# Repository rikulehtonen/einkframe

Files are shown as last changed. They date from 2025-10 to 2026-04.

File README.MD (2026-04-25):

# E-ink Art Frame - Low-Power Picture Display

A low-power digital art frame that cycles through images stored on an SD card, displayed on a 6-color e-paper screen. The display retains its image indefinitely without power, making it ideal for an always-on picture frame. Supports both Waveshare and Pimoroni Inky Impression panels.

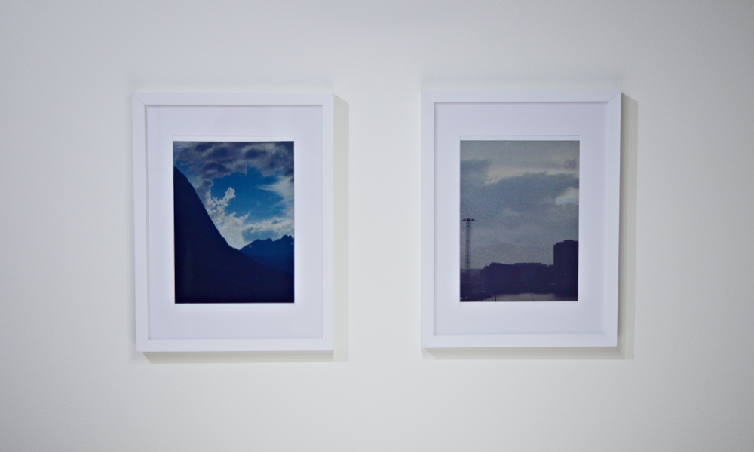
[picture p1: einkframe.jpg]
E-ink frame photo


## Features

- Cycles through images stored on a microSD card
- 6-color e-paper display: black, white, yellow, red, blue, green
- Ultra-low power — display holds image without power between updates
- Three firmware variants: 4-inch Arduino R4, 13.3-inch Waveshare ESP32, 13.3-inch Inky Impression ESP32
- Custom PCB hardware designs included

---

## Hardware Variants

### 4-inch (Waveshare EPD-4in0e) — Arduino R4
- **Resolution:** 400 × 600 px
- **Controller:** Arduino UNO R4
- **Update interval:** every 4 minutes
- Firmware: [waweshare_Arduino_R4_4inch/](waweshare_Arduino_R4_4inch/)

### 13.3-inch (Waveshare EPD-13in3e) — ESP32
- **Resolution:** 1200 × 1600 px
- **Controller:** ESP32 (with PSRAM)
- **Update interval:** every 13 hours (deep sleep between updates)
- Firmware: [waweshare_ESP32_13inch/](waweshare_ESP32_13inch/)

### 13.3-inch (Pimoroni Inky Impression) — ESP32
- **Resolution:** 1200 × 1600 px
- **Controller:** ESP32 (with PSRAM)
- **Update interval:** every 13 hours (deep sleep between updates)
- **Display:** Pimoroni Inky Impression 13.3" (uses the same underlying panel as the Waveshare variant)
- **Difference from Waveshare variant:** skips the initial screen clear before rendering, avoiding a full white flash on each update
- Firmware: [inky_ESP32_13inch/](inky_ESP32_13inch/)

---

## Repository Structure

```
├── waweshare_Arduino_R4_4inch/   # Arduino R4 firmware for 4-inch Waveshare display
├── waweshare_ESP32_13inch/       # ESP32 firmware for 13-inch Waveshare display
├── inky_ESP32_13inch/            # ESP32 firmware for 13-inch Pimoroni Inky Impression
├── image_conversion/             # Python script to convert images for the display
│   ├── convert.py
│   ├── input/                    # Place source PNG files here
│   └── output/                   # Converted .bin files are written here
├── hardware/
│   ├── controller/               # KiCad controller PCB design + gerbers
│   └── shield/                   # KiCad shield PCB design
├── documentation/                # Waveshare datasheets and manuals
└── demo/                         # Vendor-provided reference demos
```

---

## Getting Started

### 1. Convert Images

Images must be pre-converted to a packed binary format before being loaded onto the SD card.

**Requirements:** Python 3, Pillow (`pip install Pillow`)

```bash
cd image_conversion
# Place your PNG files in the input/ folder
python convert.py
# Output .bin files will appear in output/
```

The script quantizes each image to the 6-color palette, then packs 2 pixels per byte (4 bits each) to produce a `.bin` file. A palette-quantized `.bmp` preview is also saved alongside each `.bin`.

**Image dimensions must match the display:**
- 4-inch: 400 × 600 px
- 13-inch: 1200 × 1600 px

### 2. Prepare the SD Card

Copy the converted `.bin` files to the root of a FAT32-formatted microSD card, then create two text files:

**`files.txt`** — comma-separated list of filenames to display:
```
image1.bin,image2.bin,image3.bin
```

**`config.txt`** — current image index (start with `0`):
```
0
```

The firmware reads the current index from `config.txt`, displays that image, increments the index (wrapping around at the end of the list), and writes it back before sleeping.

### 3. Flash the Firmware

Open the appropriate sketch in the Arduino IDE:
- **4-inch Waveshare:** `waweshare_Arduino_R4_4inch/Arduino_R4_4inch.ino`
- **13-inch Waveshare:** `waweshare_ESP32_13inch/waweshare_ESP32_13inch.ino`
- **13-inch Inky Impression:** `inky_ESP32_13inch/inky_ESP32_13inch.ino`

Flash to your board using the Arduino IDE.

---

## Pin Connections

### Arduino R4 (4-inch display)

| Signal | Arduino Pin |
|---|---|
| SCK | 13 |
| MOSI | 11 |
| EPD CS | 10 |
| DC | 9 |
| RST | 8 |
| BUSY | 7 |
| PWR | 6 |
| SD CS | 4 |

### ESP32 (13-inch Waveshare and Inky Impression — same pins)

| Signal | ESP32 Pin |
|---|---|
| SCK | 18 |
| MOSI | 23 |
| MISO | 19 |
| EPD CS_M | 2 |
| EPD CS_S | 13 |
| DC | 14 |
| RST | 0 |
| BUSY | 26 |
| PWR | 25 |
| SD CS | 17 |

The 13-inch display uses dual SPI chip selects (CS_M and CS_S) to address the left and right halves of the panel independently.

---

## Color Palette

| Color  | 3-bit Code | RGB |
|---|---|---|
| Black  | `0x0` | (0, 0, 0) |
| White  | `0x1` | (255, 255, 255)|
| Yellow | `0x2` | (255, 255, 0)  |
| Red | `0x3` | (255, 0, 0) |
| Blue | `0x5` | (0, 0, 255) |
| Green  | `0x6` | (0, 255, 0) |

Pixels are packed two per byte: `[pixel_n (4 bits) | pixel_n+1 (4 bits)]`.

---

## Hardware

Custom PCB designs are provided in [hardware/](hardware/) (KiCad format):
- **controller/** — main controller board with gerbers ready for fabrication
- **shield/** — e-paper display shield/adapter

Waveshare schematics and datasheets are in [documentation/](documentation/).

---

## Dependencies

- [Waveshare e-Paper Arduino libraries](https://github.com/waveshareteam/e-Paper) (driver files included in each firmware folder)
- Arduino IDE with ESP32 board support (for 13-inch variant)
- Arduino UNO R4 board support (for 4-inch variant)
- Python + Pillow (for image conversion)

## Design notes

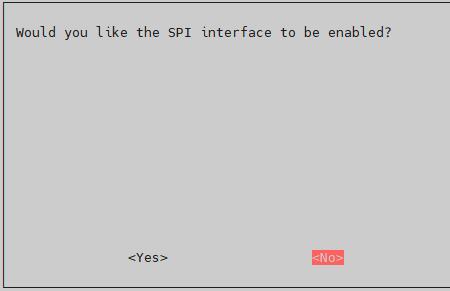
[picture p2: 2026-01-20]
documentation/waveshare_documentation_13inch/13.3inch e-Paper HAT+ (E) Manual - Waveshare Wiki_files/12.48-epaper-SPI-3.jpg

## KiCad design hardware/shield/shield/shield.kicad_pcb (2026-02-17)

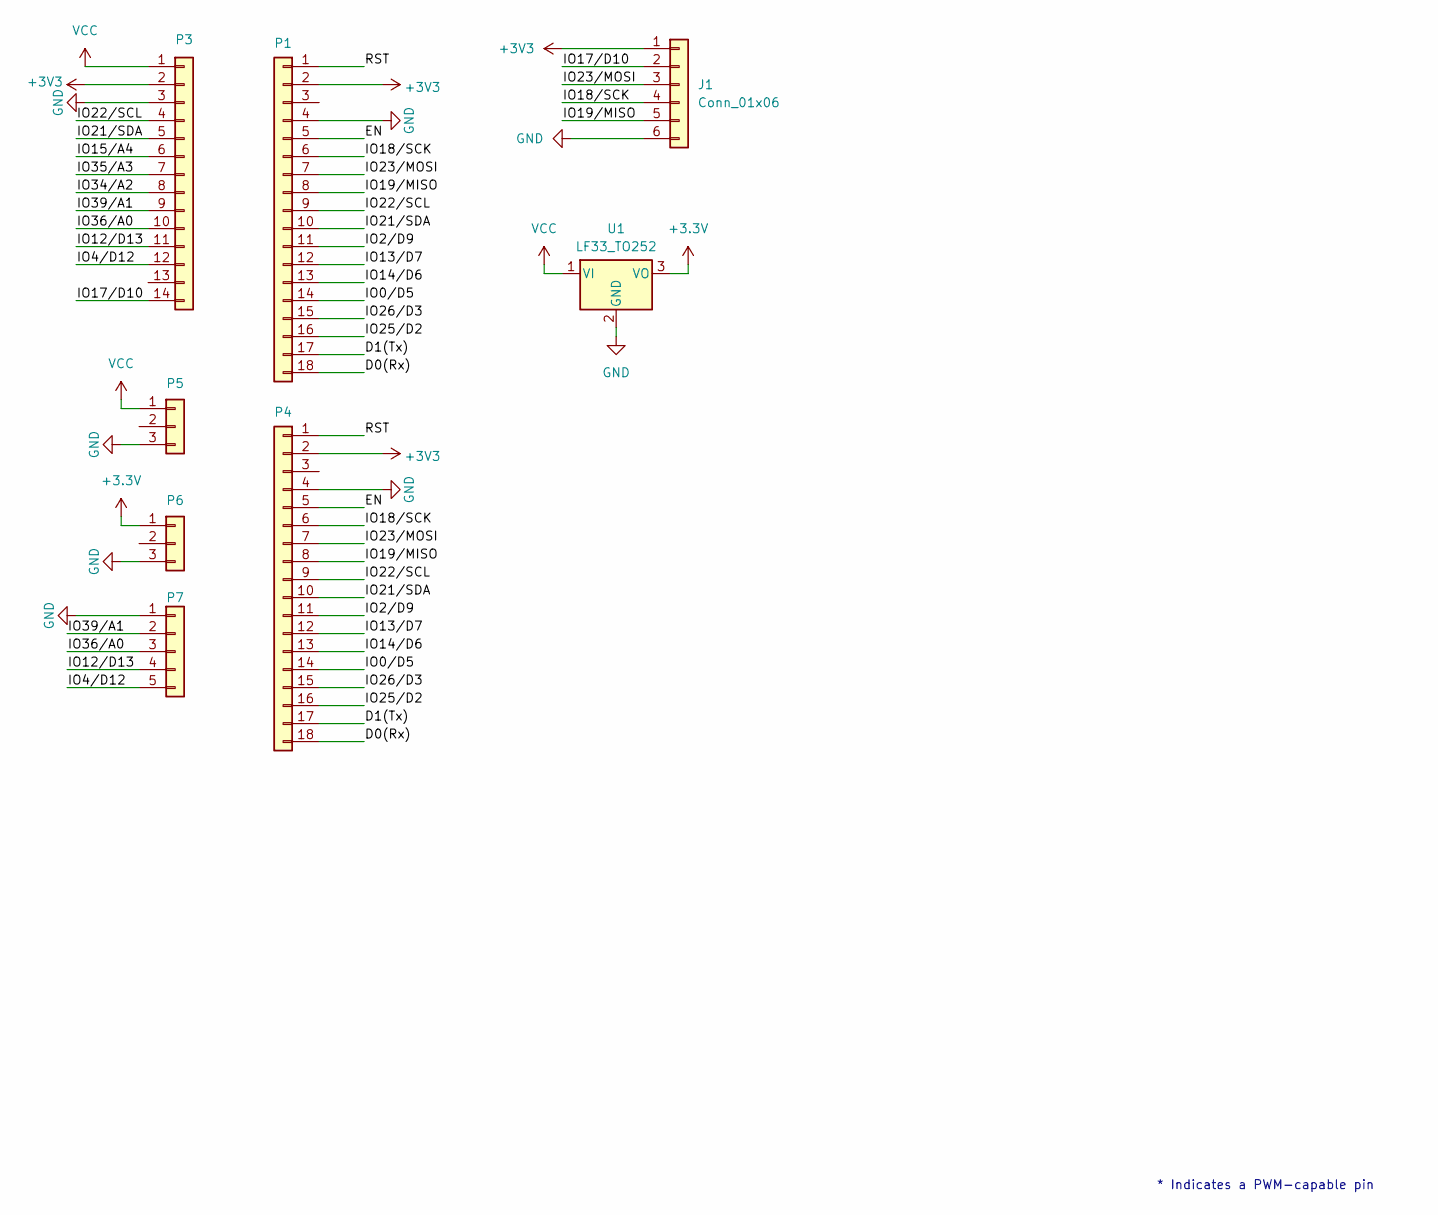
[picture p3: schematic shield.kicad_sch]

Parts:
J1: Conn_01x06; PinHeader_1x06_P2.54mm_Horizontal
P1: Digital/PWM; PinSocket_1x18_P2.54mm_Vertical
P3: PinSocket_1x14_P2.54mm_Vertical
P4: Digital/PWM; PinHeader_1x18_P2.54mm_Horizontal
P5, P6: PinHeader_1x03_P2.54mm_Horizontal
P7: PinHeader_1x05_P2.54mm_Horizontal
U1: LF33_TO252; TO-252-2

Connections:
+3.3V: P6.1, U1.3 (VO)
+3V3: J1.1, P1.2, P3.2, P4.2
/D0(Rx): P1.18, P4.18
/D1(Tx): P1.17, P4.17
/EN: P1.5, P4.5
/IO0/D5: P1.14, P4.14
/IO2/D9: P1.11, P4.11
/IO4/D12: P3.12, P7.5
/IO12/D13: P3.11, P7.4
/IO13/D7: P1.12, P4.12
/IO14/D6: P1.13, P4.13
/IO15/A4: P3.6
/IO17/D10: J1.2, P3.14
/IO18/SCK: J1.4, P1.6, P4.6
/IO19/MISO: J1.5, P1.8, P4.8
/IO21/SDA: P1.10, P3.5, P4.10
/IO22/SCL: P1.9, P3.4, P4.9
/IO23/MOSI: J1.3, P1.7, P4.7
/IO25/D2: P1.16, P4.16
/IO26/D3: P1.15, P4.15
/IO34/A2: P3.8
/IO35/A3: P3.7
/IO36/A0: P3.10, P7.3
/IO39/A1: P3.9, P7.2
/RST: P1.1, P4.1
GND: J1.6, P1.4, P3.3, P4.4, P5.3, P6.3, P7.1, U1.2 (GND)
VCC: P3.1, P5.1, U1.1 (VI)

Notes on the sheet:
* Indicates a PWM-capable pin

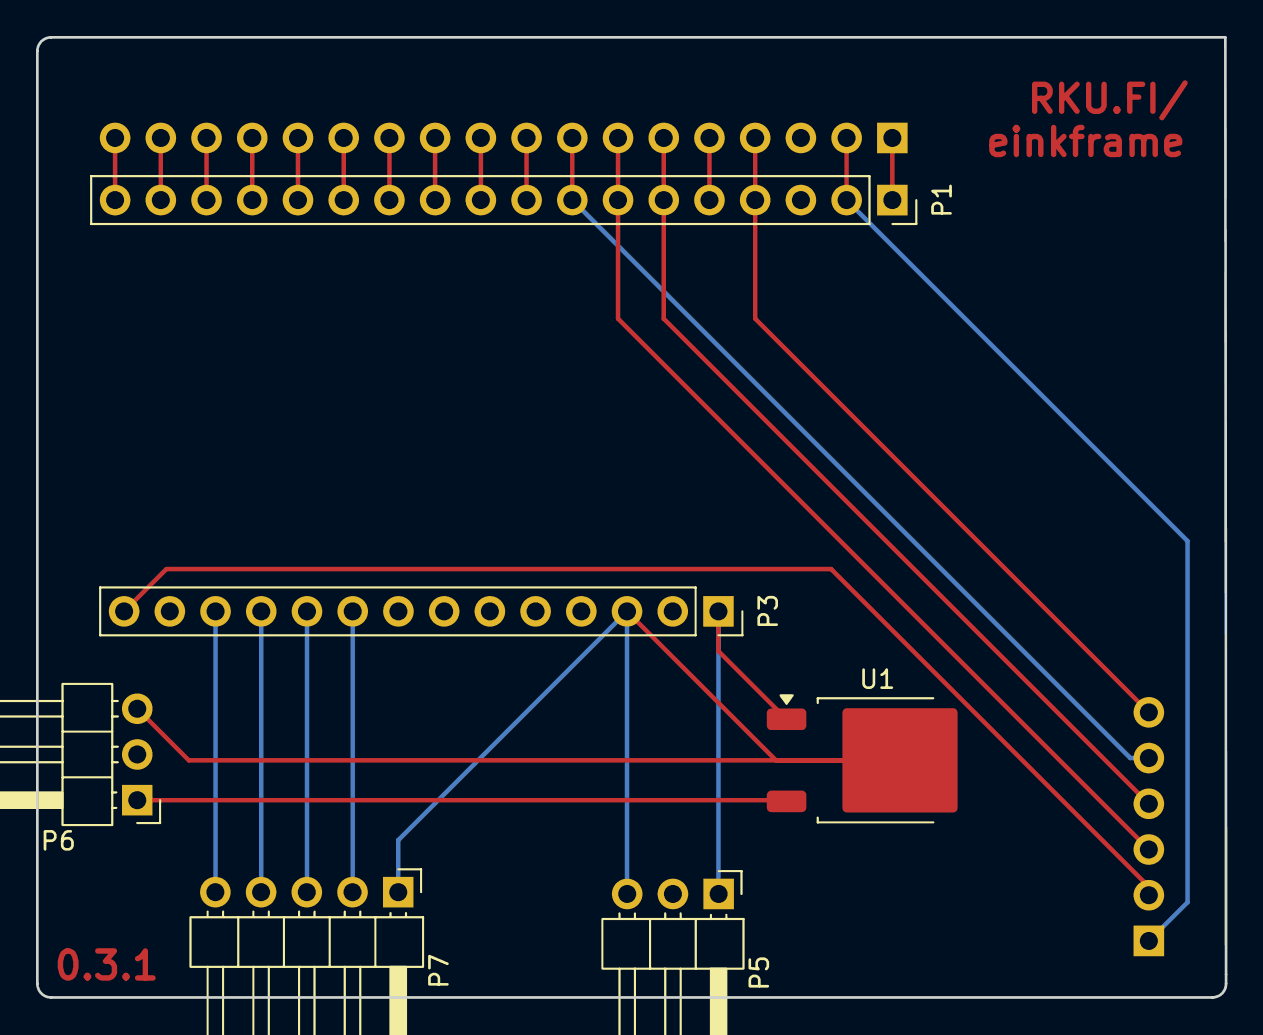
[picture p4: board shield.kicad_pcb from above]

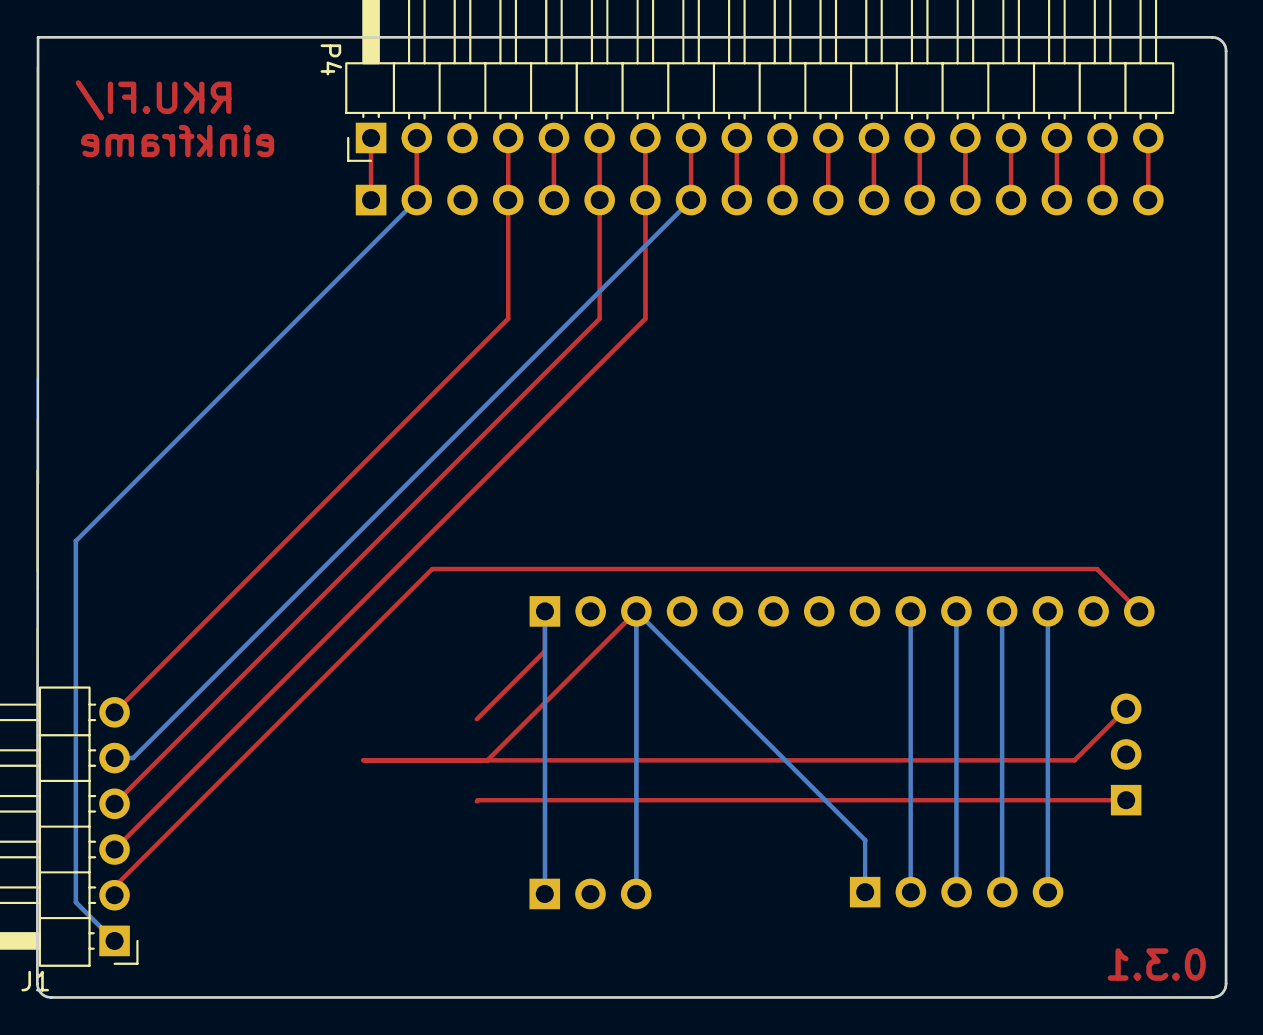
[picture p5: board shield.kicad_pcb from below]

Board: 2 copper layers, 66.0 x 53.3 mm, 8 parts (2 on the bottom side), 24 nets.

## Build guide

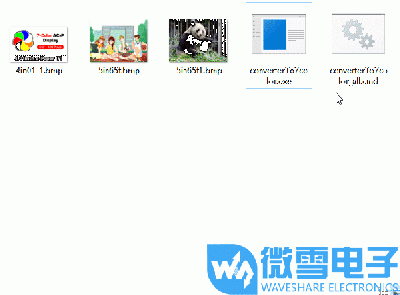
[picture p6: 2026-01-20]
documentation/waveshare_documentation_13inch/13.3inch e-Paper HAT+ (E) Manual - Waveshare Wiki_files/400px-2.36inch_e-paper_picture_make4.gif

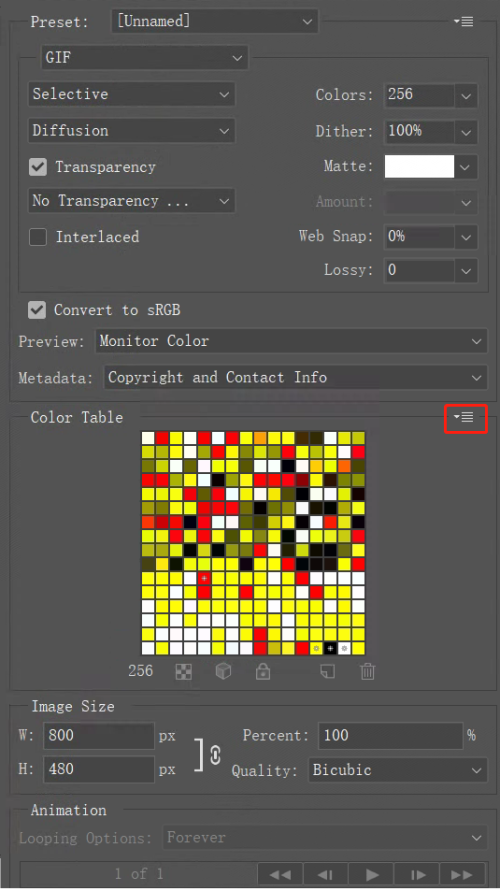
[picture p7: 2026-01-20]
documentation/waveshare_documentation_13inch/13.3inch e-Paper HAT+ (E) Manual - Waveshare Wiki_files/500px-Pica6.png

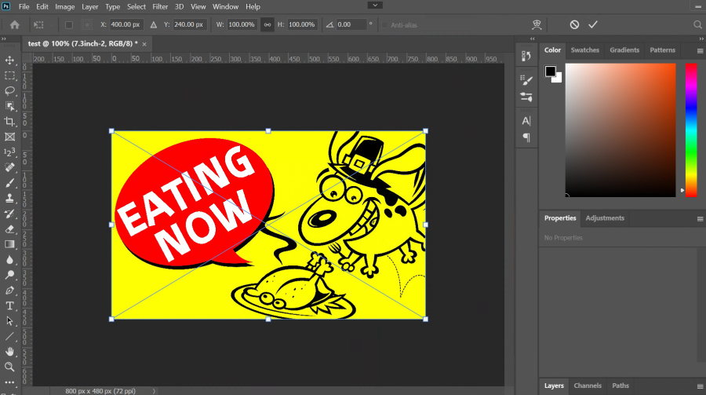
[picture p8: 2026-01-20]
documentation/waveshare_documentation_4inch/4inch e-Paper HAT+ (E) Manual - Waveshare Wiki_files/900px-Pica.png

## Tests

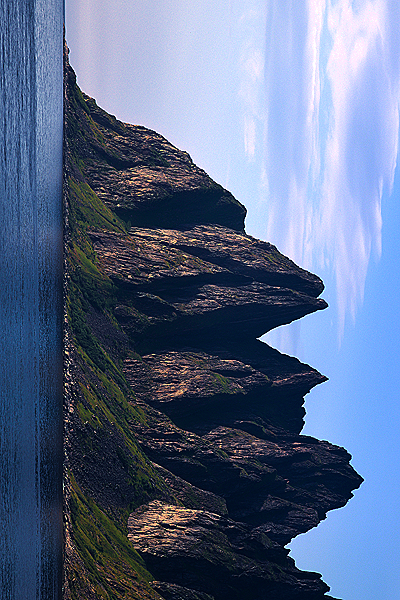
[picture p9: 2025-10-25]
demo/waweshare-RaspberryPi_JetsonNano_4inch/python/pic/test.png

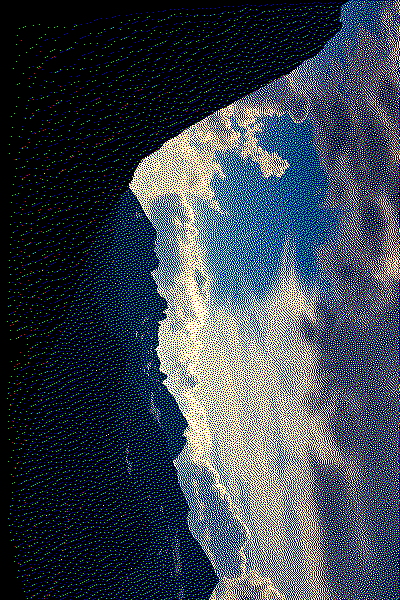
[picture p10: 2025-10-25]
demo/waweshare-RaspberryPi_JetsonNano_4inch/python/pic/test1.bmp

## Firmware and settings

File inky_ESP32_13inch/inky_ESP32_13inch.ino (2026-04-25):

/*
 * SD Card Connections:
 * pin 1 - not used          |  Micro SD card     |
 * pin 2 - CS (SS)           |                   /
 * pin 3 - DI (MOSI)         |                  |__
 * pin 4 - VDD (3.3V)        |                    |
 * pin 5 - SCK (SCLK)        | 8 7 6 5 4 3 2 1   /
 * pin 6 - VSS (GND)         | ▄ ▄ ▄ ▄ ▄ ▄ ▄ ▄  /
 * pin 7 - DO (MISO)         | ▀ ▀ █ ▀ █ ▀ ▀ ▀ |
 * pin 8 - not used          |_________________|
 * 
 * Note: Use `SPI.begin(sck, miso, mosi, cs)` to manually configure SPI pins.
 */

#include "EPD_13in3e.h"
//#include "GUI_Paint.h"
#include "Debug.h"
#include "DEV_Config.h"

#include "FS.h"
#include "SD.h"
#include "SPI.h"

#define uS_TO_S_FACTOR 1000000ULL /* Conversion factor for micro seconds to seconds */
#define TIME_TO_SLEEP  60*60*13          /* Time ESP32 will go to sleep (in seconds) */

// Uncomment and set up if you want to use custom pins for the SPI communication
int sck = 18;
int miso = 19;
int mosi = 23;
int cs = 17;

File f;
int g_current_file_index = 0;  // Global to track which file number we're on

void setup() {
    Serial.begin(115200);
    DEV_Delay_ms(3000);
    Debug("EPD_13IN3E_test Demo\r\n");
    DEV_Module_Init();
    EPD_13IN3E_Init();
    int sd_init_retries = 0;
    const int MAX_SD_RETRIES = 5;
    const int SD_RETRY_DELAY = 500; // milliseconds
    

    while (!SD.begin(cs) && sd_init_retries < MAX_SD_RETRIES) {
        Serial.printf("SD Card Mount Failed (attempt %d/%d), retrying...\n", sd_init_retries + 1, MAX_SD_RETRIES);
        DEV_Delay_ms(SD_RETRY_DELAY);
        sd_init_retries++;
    }

    if (sd_init_retries >= MAX_SD_RETRIES) {
        Serial.println("Card Mount Failed");
    }
    else {
        // Get and print the next file
        String nextFile = getNextFile();
        Serial.printf("Processing file: %s\n", nextFile.c_str());
        // Clear screen every 5 files (index 0, 5, 10, etc.)
        if (g_current_file_index % 5 == 0) {
            EPD_13IN3E_Clear(EPD_13IN3E_WHITE);
        }
        render("/" + nextFile);
    }

    Debug("Goto Sleep...\r\n");
    EPD_13IN3E_Sleep();
    // close 5V
    Debug("close 5V, Module enters 0 power consumption ...\r\n");
    DEV_Module_Exit();
    
    //Deep sleep
    esp_sleep_enable_timer_wakeup(TIME_TO_SLEEP * uS_TO_S_FACTOR);
    Serial.println("Setup ESP32 to sleep for every " + String(TIME_TO_SLEEP) + " Seconds");
    Serial.println("Going to sleep now");
    Serial.flush();
    esp_deep_sleep_start();

}

String getNextFile() {
    int config_index = 0;
    String file_name = "";

    // Read index from config.txt
    File f = SD.open("/config.txt", FILE_READ);
    if (f) {
        String index_string = "";
        while (f.available()) {
            index_string += (char)f.read();
        }
        f.close();
        config_index = index_string.toInt();
    } else {
        Serial.println("Error opening config.txt for reading");
    }

    // Open files list
    f = SD.open("/files.txt", FILE_READ);
    if (f) {
        int current_file_index = 0;
        while (f.available() && current_file_index <= config_index) {
            file_name = f.readStringUntil(',');
            current_file_index++;
        }

        // If we've reached the end, wrap around
        if (!f.available()) {
            config_index = 0;
        } else {
            config_index++;
        }

        f.close();
    } else {
        Serial.println("Error opening files.txt");
    }

    // Write back updated index
    SD.remove("/config.txt");
    f = SD.open("/config.txt", FILE_WRITE);
    if (f) {
        f.print(config_index);
        f.close();
    } else {
        Serial.println("Error opening config.txt for writing");
    }

    // Store the current index globally
    g_current_file_index = config_index;

    // Print the next file name
    Serial.printf("Next file: %s\n", file_name.c_str());
    return file_name;
}


void render(String file_name){
    
    UDOUBLE Width, Width1, Height;
    UBYTE Color;
    Width = (EPD_13IN3E_WIDTH % 2 == 0)? (EPD_13IN3E_WIDTH / 2 ): (EPD_13IN3E_WIDTH / 2 + 1);
    Width1 = (Width % 2 == 0)? (Width / 2 ): (Width / 2 + 1);
    Height = EPD_13IN3E_HEIGHT;
    Color = (EPD_13IN3E_WHITE<<4)|EPD_13IN3E_WHITE;

    UBYTE padding[Width1];
    
    for (UDOUBLE j = 0; j < Width/2; j++) {
        padding[j] = Color;
    }

    DEV_Delay_ms(5000);
    Debug("EPD_13IN3E_test Demo\r\n");
    //EPD_13IN3E_Clear(EPD_13IN3E_WHITE);

    if(psramInit()){
        Serial.println("\nPSRAM is correctly initialized");
    }else{
        Serial.println("PSRAM not available");
    }

    UDOUBLE n = 0;
    // Read index from config.txt
    UBYTE *buf = (UBYTE *)ps_malloc((Width)*EPD_13IN3E_HEIGHT);

    File f = SD.open(file_name, FILE_READ);
    if(f.available()) {
        Serial.print("Buffer contents: ");
        for (UDOUBLE j = 0; j < EPD_13IN3E_HEIGHT; j++) {
            size_t bytesRead = f.read(buf + j*Width, Width);
        }
        //for (UDOUBLE i = 0; i < Width; i++) {
        //    Serial.printf("0x%02X ", buf[i]);
        //}
        //Serial.println();
    } else {
        Serial.println("FAILED");
    }
    f.close();


    DEV_Digital_Write(EPD_CS_M_PIN, 0);
    EPD_13IN3E_SendCommand(0x10);
    for (UDOUBLE j=0; j<Height; j++) {
        EPD_13IN3E_SendData2(buf + j*Width, Width1);
        DEV_Delay_ms(1);
    }
    EPD_13IN3E_CS_ALL(1);

    DEV_Digital_Write(EPD_CS_S_PIN, 0);
    EPD_13IN3E_SendCommand(0x10);
    for (UDOUBLE j=0; j<Height; j++) {
        EPD_13IN3E_SendData2(buf + j*Width + Width1, Width1);
        DEV_Delay_ms(1);
    }
    EPD_13IN3E_CS_ALL(1);
    DEV_Delay_ms(1000);


    EPD_13IN3E_TurnOnDisplay();
    free(buf);
}

void loop() {}

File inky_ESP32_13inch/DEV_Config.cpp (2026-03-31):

/*****************************************************************************
* | File      	:   DEV_Config.c
* | Author      :   Waveshare team
* | Function    :   Hardware underlying interface
* | Info        :
*----------------
* |	This version:   V1.0
* | Date        :   2020-02-19
* | Info        :
#
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
******************************************************************************/
#include "DEV_Config.h"
#include <SPI.h>

void GPIO_Config(void)
{
    // Configure pins. Busy line needs a pull-up so it doesn't float
    pinMode(EPD_BUSY_PIN,  INPUT_PULLUP);

    pinMode(EPD_RST_PIN , OUTPUT);
    pinMode(EPD_DC_PIN  , OUTPUT);
    pinMode(EPD_PWR_PIN,  OUTPUT);

    pinMode(EPD_SCK_PIN, OUTPUT);
    pinMode(EPD_MOSI_PIN, OUTPUT);
    pinMode(EPD_MISO_PIN, INPUT);
    pinMode(EPD_CS_M_PIN , OUTPUT);
    pinMode(EPD_CS_S_PIN , OUTPUT);

    // Set sensible initial output levels
    digitalWrite(EPD_CS_M_PIN , HIGH);
    digitalWrite(EPD_CS_S_PIN , HIGH);
    digitalWrite(EPD_SCK_PIN, HIGH);
    digitalWrite(EPD_PWR_PIN , HIGH);
    // Ensure DC and RST are in known states
    digitalWrite(EPD_DC_PIN, LOW);
    //digitalWrite(EPD_RST_PIN, HIGH);
}

void GPIO_Mode(UWORD GPIO_Pin, UWORD Mode)
{
    if(Mode == 0) {
        pinMode(GPIO_Pin , INPUT);
	} else {
		pinMode(GPIO_Pin , OUTPUT);
	}
}
/******************************************************************************
function:	Module Initialize, the BCM2835 library and initialize the pins, SPI protocol
parameter:
Info:
******************************************************************************/
UBYTE DEV_Module_Init(void)
{
	//gpio
	GPIO_Config();

	//serial printf
	//Serial.begin(115200);

    // Initialize hardware SPI on the pins used for the EPD
    // (SCK, MISO, MOSI)
    SPI.begin(EPD_SCK_PIN, EPD_MISO_PIN, EPD_MOSI_PIN);

	return 0;
}

/******************************************************************************
function:
			SPI read and write
******************************************************************************/


void DEV_SPI_WriteByte(UBYTE data)
{
    SPI.beginTransaction(SPISettings(4000000, MSBFIRST, SPI_MODE0));
    SPI.transfer(data);
    SPI.endTransaction();

}

UBYTE DEV_SPI_ReadByte()
{
    SPI.beginTransaction(SPISettings(4000000, MSBFIRST, SPI_MODE0));
    uint8_t val = SPI.transfer(0x00);
    SPI.endTransaction();
    return val;
}

void DEV_SPI_Write_nByte(UBYTE *pData, UDOUBLE len)
{
    SPI.beginTransaction(SPISettings(4000000, MSBFIRST, SPI_MODE0));
    for (UDOUBLE i = 0; i < len; i++) {
        SPI.transfer(pData[i]);
    }
    SPI.endTransaction();
}


void DEV_Module_Exit(void)
{
    digitalWrite(EPD_PWR_PIN , LOW);
    digitalWrite(EPD_RST_PIN , LOW);
}

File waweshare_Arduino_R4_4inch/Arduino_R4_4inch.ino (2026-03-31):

#include "EPD_4in0e.h"
#include "GUI_Paint.h"
#include <SPI.h>
#include <SD.h>
//#include "fonts.h"
//#include "ImageData.h"

File myFile;

// Convert RGB to nearest supported e-paper color
UBYTE bmpColorToEPD(uint8_t r, uint8_t g, uint8_t b) {
    if (r < 50 && g < 50 && b < 50) return EPD_4IN0E_BLACK;     // black
    if (r > 200 && g > 200 && b > 200) return EPD_4IN0E_WHITE;  // white
    if (r > 200 && g > 200 && b < 80) return EPD_4IN0E_YELLOW;  // yellow
    if (r > 200 && g < 80 && b < 80) return EPD_4IN0E_RED;      // red
    if (r < 80 && g < 80 && b > 200) return EPD_4IN0E_BLUE;     // blue
    if (r < 80 && g > 200 && b < 80) return EPD_4IN0E_GREEN;    // green
    return EPD_4IN0E_WHITE; // fallback
}

void setup() {

    while (!Serial) {
        ; // wait for serial port to connect. Needed for native USB port only
    }
	Serial.begin(115200);

    Serial.print("Initializing SD card...");

    if (!SD.begin(4)) {
        Debug("initialization failed!");
        while (1);
    }
    Debug("initialization done.");
}


void loop() {
    String file_name = getNextFile();
    render(file_name);
    //Serial.println("Sleeping");
    delay(1000UL * 60 * 4);
    //Serial.println("Sleeping complete");
}


String getNextFile() {
    int config_index = 0;
    String file_name = "";

    // Read index from config.txt
    myFile = SD.open("config.txt");
    if (myFile) {
        String index_string = "";
        while (myFile.available()) {
            index_string += (char)myFile.read();
        }
        myFile.close();
        config_index = index_string.toInt();
    } else {
        Serial.println("error opening config.txt");
    }

    // Open files list
    myFile = SD.open("files.txt");
    if (myFile) {
        int current_file_index = 0;
        while (myFile.available() && current_file_index <= config_index) {
            file_name = myFile.readStringUntil(',');
            current_file_index++;
        }

        // If we've reached the end, wrap around
        if (!myFile.available()) {
            config_index = 0;
        } else {
            config_index++;
        }

        myFile.close();
    } else {
        Serial.println("error opening files.txt");
    }

    // Write back updated index
    SD.remove("config.txt");
    myFile = SD.open("config.txt", FILE_WRITE);
    if (myFile) {
        myFile.print(config_index);
        myFile.close();
    } else {
        Serial.println("error opening config.txt for write");
    }

    return file_name;
}



void render(String file_name){
    
    Debug("EPD_4IN0E_test Demo\r\n");
    DEV_Module_Init();

    Debug("e-Paper Init and Clear...\r\n");
    EPD_4IN0E_Init();
    EPD_4IN0E_Clear(EPD_4IN0E_WHITE);
    DEV_Delay_ms(500);

    // unsigned long j, k;
    unsigned char const Color_seven[6] = 
    {EPD_4IN0E_BLACK, EPD_4IN0E_YELLOW, EPD_4IN0E_RED, EPD_4IN0E_BLUE, EPD_4IN0E_GREEN, EPD_4IN0E_WHITE};

    // re-open the file for reading:
    myFile = SD.open(file_name);
    if (myFile) {
        EPD_4IN0E_SendCommand(0x10);
        // read from the file until there's nothing else in it:
        int n = 0;
        while (myFile.available() && n < 50000) {
            const UBYTE c = myFile.read();
            if (c != -1) {                
                //Debug(c);
                //Debug(" ");
                EPD_4IN0E_SendData(c);
                n += 1;
            }
        }

        // close the file:
        myFile.close();
        // Render image to the display
        EPD_4IN0E_TurnOnDisplay();
    } else {
        // if the file didn't open, print an error:
        Debug("error opening image");
    }

    Debug("Goto Sleep...\r\n");
    EPD_4IN0E_Sleep();
    DEV_Delay_ms(2000);

    // close 5V
    Debug("close 5V, Module enters 0 power consumption ...\r\n");
    DEV_Module_Exit();
}

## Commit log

2025-11-12 add sd card reader for esp32
2025-12-28 eink update cycle fix
    [DEV_Config.cpp, DEV_Config.h]
2026-01-10 add retry for sd attach and 12h sleep
2026-01-23 add hardware files
    [controller.kicad_pcb, controller.kicad_sch]
2026-01-30 add kicad files
    [controller.kicad_pcb, shield.kicad_pcb, shield.kicad_sch]
2026-01-31 add pins for in/out
    [shield.kicad_pcb, shield.kicad_sch]
2026-02-01 add gerbers
    [shield-B_Cu.gbl, shield-B_Mask.gbs, shield-B_Paste.gbp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]
2026-02-01 add shield 0.3.1 version
    [shield.kicad_pcb, shield.kicad_sch]
2026-02-17 remove backups
    [controller.kicad_pcb, controller.kicad_sch]
2026-03-03 fix delay order for debug
    [inky_ESP32_13inch.ino]
